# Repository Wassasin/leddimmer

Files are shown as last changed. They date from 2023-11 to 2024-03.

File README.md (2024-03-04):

# LED PWM dimmer
Quick low-side PWM device to crudely dim two 24V 4A LED strips.

Uses ESP32-C3 LEDC peripheral to provide the PWM signal, and uses two low side gate drivers to pull a N-channel Mosfet. Uses high side current limiters and fuses as protection.

## TODO
* 100K Pull-up esp32 enable
* 100K Pull-downs for drv-enable
* 47nF filter voor isense
* Swap drv2 isense en drvsense
* WS2812B data line on 3V3
* Status line high side driver useless without output voltages
* Caps C5750X7R1V476M230KC / 47uF 35V X7R 2220

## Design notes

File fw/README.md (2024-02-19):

## Dependencies
This project uses the Espressif [ESP-IDF version 5.1.1 for the ESP32S3](https://docs.espressif.com/projects/esp-idf/en/v5.1.1/esp32s3/get-started/index.html).

### Nix
Optionally you can use Nix to initialize a shell.

Firstly you require Nix to be installed, and to have the following optional features enabled (in `~/.config/nix/nix.conf`):
```
experimental-features = nix-command flakes
```

Then you can run in the top-level directory of this repository:
```bash
nix develop
```

All the required dependencies should now be loaded in this shell.

## How to build
```bash
rm ./sdkconfig
export SDKCONFIG_DEFAULTS="./sdkconfig.default"
idf.py clean
rm -rf build

idf.py menuconfig
# Now set all required options under Leddimmer

idf.py build
```

## How to flash
Connect the device over USB-C to your computer and run
```bash
idf.py flash
```

You can attach to the virtual terminal of the device by running
```bash
idf.py monitor
```

For more information to use this monitor, see the [ESP-idf documentation on monitor](https://docs.espressif.com/projects/esp-idf/en/release-v5.1/esp32s3/api-guides/tools/idf-monitor.html).

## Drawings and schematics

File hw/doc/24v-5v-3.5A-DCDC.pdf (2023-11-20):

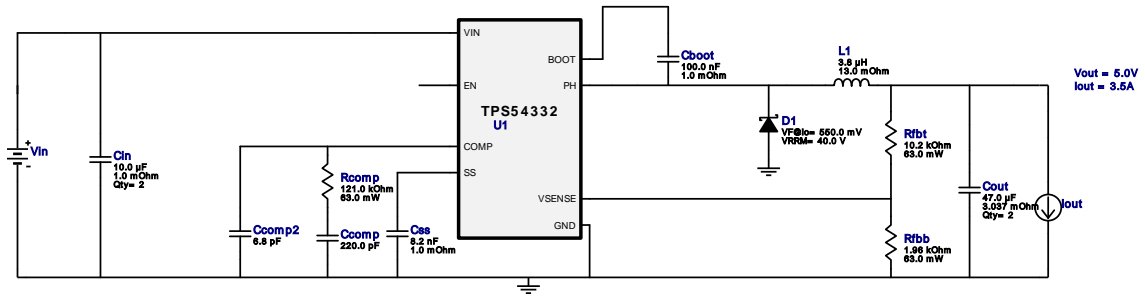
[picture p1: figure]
Css 8.2 nF 1.0 m Ohm; Ccom p2 6.8 pF; TPS5 4 3 3 2; BOOT; VIN; VSENSE; COMP; GND; Rfbb 1.96 kOhm 63.0 m W; Cboot 100.0 nF 1.0 m Ohm; Cin 10.0 µF 1.0 m Ohm Qty= 2; L1 3.8 µH 13.0 m Ohm; Rfbt 10.2 kOhm 63.0 m W; Cout 47.0 µF 3.037 m Ohm Qty= 2; D1 VF@Io= 550.0 m V VRRM= 40.0 V; Ccom p 220.0 pF; Rcom p 121.0 kOhm 63.0 m W; Vout = 5.0V Iout = 3.5A; Iout; Vin

Copyright © 2023, Texas Instruments Incorporated | 1 | ti.com/webench

WEBENCH®
Design Report TPS54332DDAR : TPS54332DDAR 23V-25V to 5.00V @ 3.5A November 18, 2023 08:35:46 GMT-06:00

## WEBENCH ® Design Report

Design : 88 TPS54332DDAR
TPS54332DDAR 23V-25V to 5.00V @ 3.5A

VinMin = 23.0V
VinMax = 25.0V
Vout = 5.0V
Iout = 3.5A

Device = TPS54332DDAR
Topology = Buck
Created = 2023-11-18 08:24:08.620 BOM Cost = $2.37
BOM Count = 14
Total Pd = 2.56W

## Electrical BOM

Name | Manufacturer | Part Number | Properties | Qty Price | Footprint
Cboot | MuRata | GRM155R71A104KA01D (http://search.murata.co.jp/Ceramy/PnsearchViewAction.do) Series= X7R | Cap= 100.0 nF ESR= 1.0 mOhm VDC= 10.0 V IRMS= 0.0 A
1 | $0.01
| | | | | 0402 3 mm²
Ccomp | Samsung Electro- Mechanics | CL21C221JBANNNC (http://www.samsungsem.com/servlet/FileDownload?type%3Dspec%26file%3DCL21C221JBANNNC.pdf) Series= C0G/NP0

Cap= 220.0 pF
VDC= 50.0 V
IRMS= 0.0 A

1 $0.01
0805 7 mm²
Ccomp2 | AVX | 06031U6R8BAT2A (http://www.avx.com/docs/Catalogs/ccog.pdf) Series= C0G/NP0

Cap= 6.8 pF
VDC= 100.0 V
IRMS= 0.0 A

1 $0.05
0603 5 mm²
Cin | TDK | C3225X7R1H106M250AC Series= X7R

Cap= 10.0 uF
ESR= 1.0 mOhm
VDC= 50.0 V
IRMS= 5.0 A

2 $0.27
1210 15 mm²
Cout | MuRata | GRM32ER61C476KE15L (http://psearch.en.murata.com/capacitor/result/smd/?status%3Dall%26pid%3DGRM32ER61C476KE15L) Series= X5R

Cap= 47.0 uF
ESR= 3.037 mOhm
VDC= 16.0 V
IRMS= 4.59346 A

2 $0.17
1210_280 15 mm²
Css | MuRata | GRM033R71A822KA01D (http://search.murata.co.jp/Ceramy/PnsearchViewAction.do) Series= X7R

Cap= 8.2 nF
ESR= 1.0 mOhm
VDC= 10.0 V
IRMS= 0.0 A

1 $0.01
0201 2 mm²
D1 | Diodes Inc. | B540C-13-F (http://www.diodes.com/datasheets/ds13012.pdf) | VF@Io= 550.0 mV VRRM= 40.0 V
1 | $0.19

SMC 83 mm²
L1 | Coiltronics | DR1040-3R8-R (http://www.cooperindustries.com/content/dam/public/bussmann/Electronics/Resources/Data%20Sheets/Bus%5FElx%5FDS%5FPM%204147%5FDR1040%5FSeries.pdf) | L= 3.8 µH 13.0 mOhm
1 | $0.49

DR1040 154 mm²
Rcomp | Vishay-Dale | CRCW0402121KFKED (http://www.vishay.com/docs/20035/dcrcwe3.pdf) Series= CRCW..e3

Res= 121.0 kOhm
Power= 63.0 mW
Tolerance= 1.0%

1 $0.01
0402 3 mm²
Rfbb | Vishay-Dale | CRCW04021K96FKED (http://www.vishay.com/docs/20035/dcrcwe3.pdf) Series= CRCW..e3

Res= 1.96 kOhm
Power= 63.0 mW
Tolerance= 1.0%

1 $0.01
0402 3 mm²

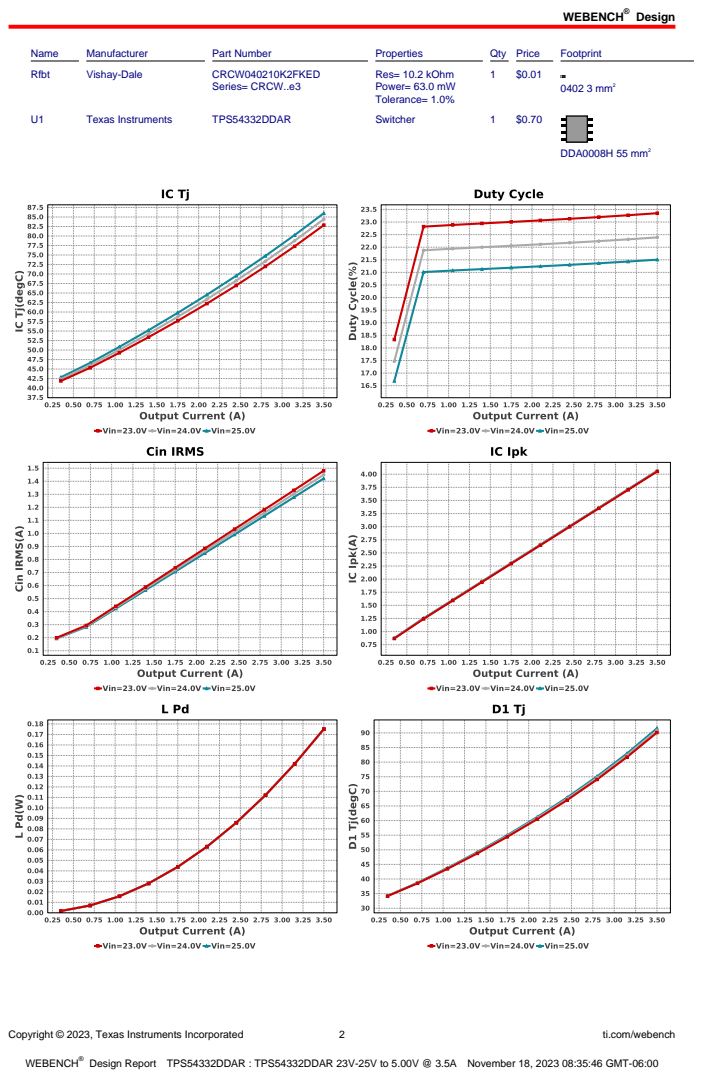
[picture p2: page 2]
Design; Copyright © 2023, Texas Instruments Incorporated; ti.com/webench; Name; Manufacturer; Part Number; Properties; Qty Price; Footprint; Rfbt; Vishay-Dale; CRCW040210K2FKED; Series= CRCW..e3; Res= 10.2 kOhm Power= 63.0 mW Tolerance= 1.0%; 0402 3 mm²; Texas Instruments; TPS54332DDAR; Switcher; DDA0008H 55 mm²

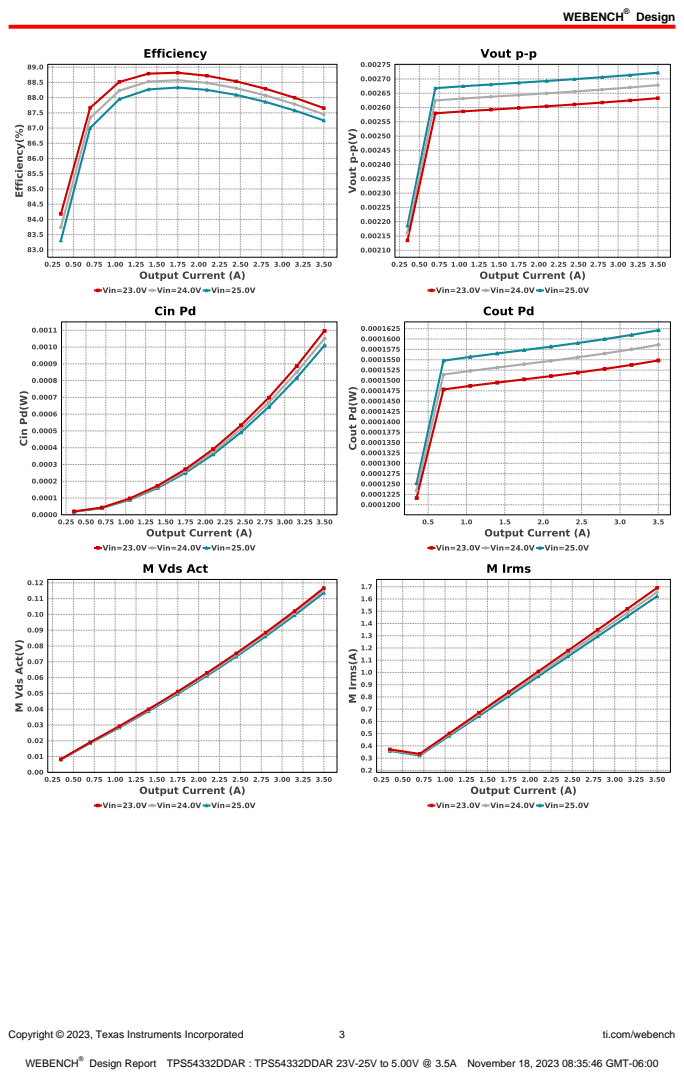
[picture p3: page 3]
Copyright © 2023, Texas Instruments Incorporated; ti.com/webench

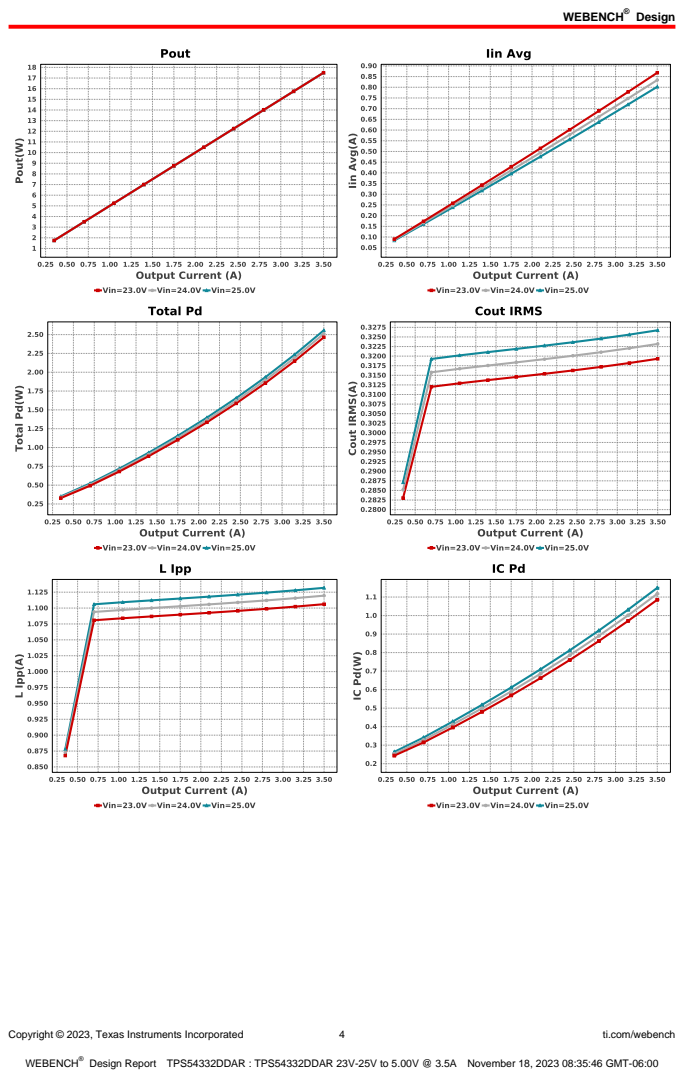
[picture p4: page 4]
Copyright © 2023, Texas Instruments Incorporated; ti.com/webench

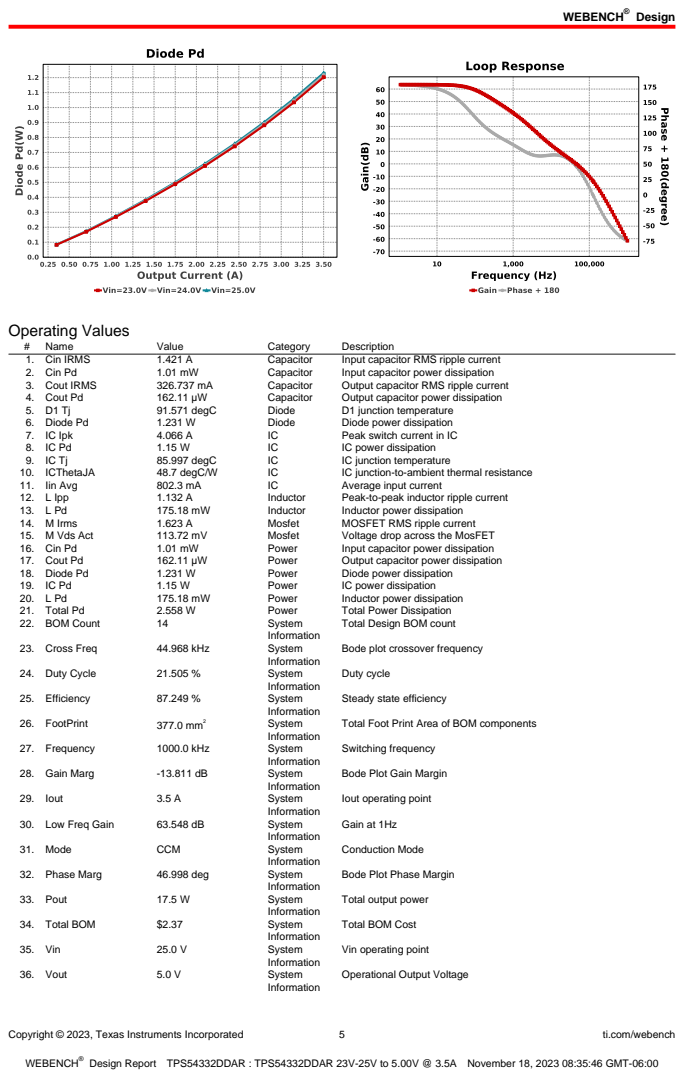
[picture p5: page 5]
Copyright © 2023, Texas Instruments Incorporated; ti.com/webench; Operating Values; Name; Value; Category; Description; 1. Cin IRMS; Capacitor; Input capacitor RMS ripple current; 2. Cin Pd; Input capacitor power dissipation; 3. Cout IRMS; Output capacitor RMS ripple current; 4. Cout Pd; Output capacitor power dissipation; 91.571 degC; Diode; D1 junction temperature; 6. Diode Pd; Diode power dissipation; 7. IC Ipk; Peak switch current in IC; IC power dissipation; 85.997 degC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

Total Design BOM count

Bode plot crossover frequency

Steady state efficiency

Total Foot Print Area of BOM components

Bode Plot Gain Margin

Iout operating point

Bode Plot Phase Margin

Total output power

Total BOM Cost

Vin operating point

Operational Output Voltage

Copyright © 2023, Texas Instruments Incorporated | 6 | ti.com/webench
# | Name | Value | Category | Description

37. Vout Actual | 4.963 V | System
| | | Information | Vout Actual calculated based on selected voltage divider resistors
38. Vout Tolerance | 5.254 % | System
| | | Information | Vout Tolerance based on IC Tolerance (no load) and voltage divider resistors if applicable
39. Vout p-p | 2.722 mV | System
| | | Information | Peak-to-peak output ripple voltage
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

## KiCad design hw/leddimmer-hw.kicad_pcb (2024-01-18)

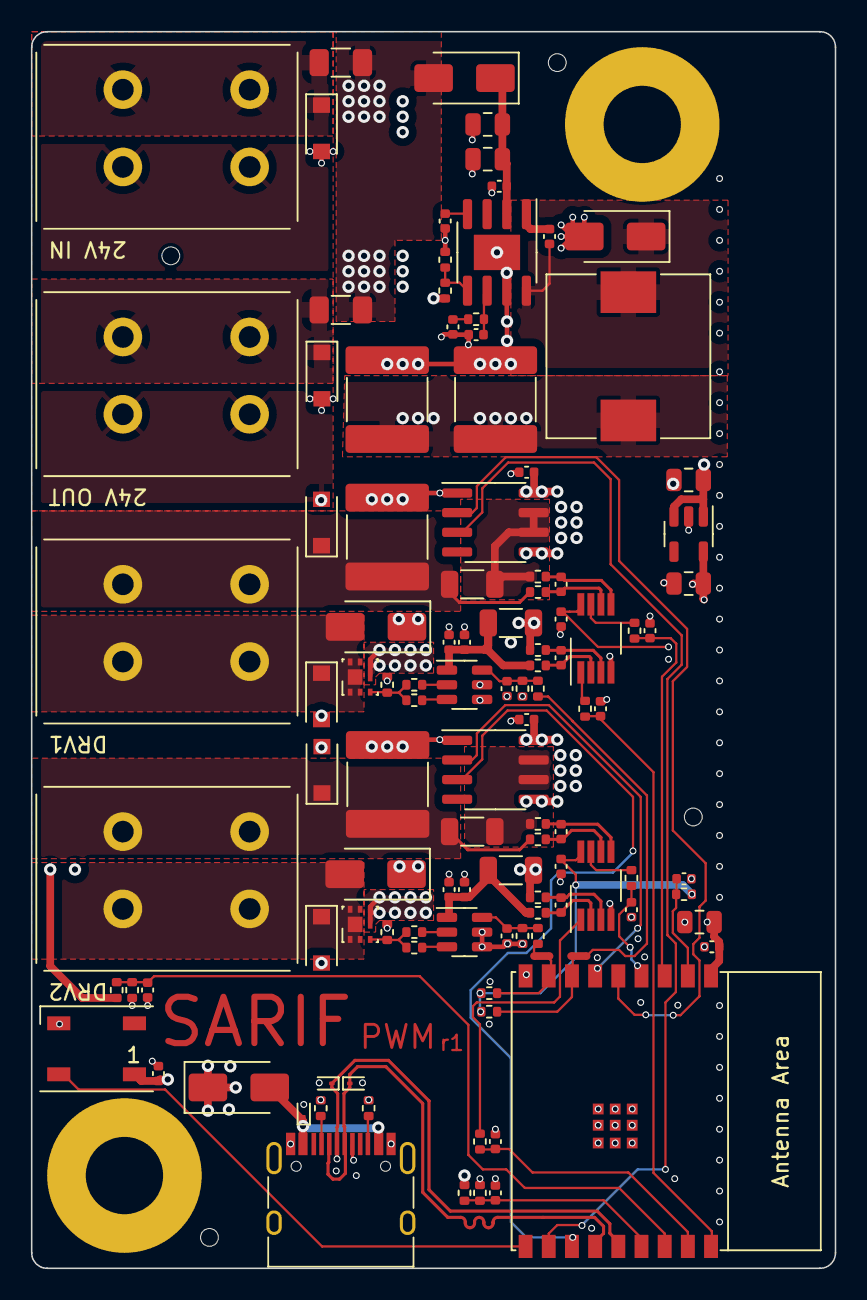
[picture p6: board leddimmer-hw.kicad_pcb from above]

Board: 4 copper layers, 52.0 x 80.0 mm, 117 parts (0 on the bottom side), 62 nets.

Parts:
C201, C204, C210, C301, C304, C310, C509, C601, C603, C604, C605, C606: 100nF; C_0402_1005Metric
C202, C205, C206, C302, C305, C306: C_0402_1005Metric
C203, C303, C505: 1uF; C_0402_1005Metric
C207, C307, C510, C511: 47uF; C_2220_5750Metric
C208, C209, C308, C309, C501: 6.8nF; C_0402_1005Metric
C502, C504, C602: 10uF; C_0805_2012Metric
C503: 220pF; C_0402_1005Metric
C506: 8.2nF; C_0402_1005Metric
C507, C508: 10u; C_0805_2012Metric
D201, D301, D501, D502, D503: SS54; D_SMA
D401: ESD9X5.0ST5G; D_SOD-923
D402, D403: ESD9L3.3ST5G; D_SOD-923
D404, D405, D406, D407, D408, D409: SJD12A28L01; D_SOD-123S
D601: WS2812B; LED_WS2812B_PLCC4_5.0x5.0mm_P3.2mm
F401, F402: 0501010.WR1; Fuse_1206_3216Metric
H101, H102, H103, H104: ToolingHole; JLCPCB tooling hole
H105, H106: MountingHole; MountingHole_5mm_Keepout
J401, J402, J403, J404: 2604-1102; WAGO-2604-1102
L501: SDSL10D40F-3R8Y; L_10.4x10.4_H4.8
NT601, NT602: NetTie_2; NetTie-2_SMD_Pad0.5mm
P401: TYPE-C-31-M-12; USB_C_Receptacle_HRO_TYPE-C-31-M-12
Q201, Q301: CSD17571Q2
R201, R203, R204, R207, R208, R209, R210, R301, R303, R304, R307, R308, R309, R310: 1Ohm; R_0402_1005Metric
R202, R211, R302, R311, R601, R602, R603, R604, R606: 100kOhm; R_0402_1005Metric
R205, R206, R305, R306: 3mR 1%; R_1206_3216Metric
R212, R213, R312, R313, R401, R402: 5.1kOhm; R_0402_1005Metric
R501: 121kOhm; R_0402_1005Metric
R502, R607: 10.2kOhm; R_0402_1005Metric
R503, R605: 1.96kOhm; R_0402_1005Metric
U201, U301: NCV8460A; SOIC-8_3.9x4.9mm_P1.27mm
U202, U302: UCC27511DBVR; SOT-23-6
U203, U303: INA2180A2IDGKR; VSSOP-8_3.0x3.0mm_P0.65mm
U501: TPS54332DDAR; SOIC-8-1EP_3.9x4.9mm_P1.27mm_EP2.29x3mm
U502: AP2112K-3.3; SOT-23-5
U601: ESP32-C3-WROOM-02

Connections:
+3V3: C210.1, C310.1, C508.1, C602.1, C603.1, R601.2, R602.2, R603.2, U203.8 (VS), U303.8 (VS), U502.5 (VOUT), U601.1 (3V3)
+5V: C507.1, C510.1, C511.1, C604.1, D502.1 (K), D601.1 (VDD), L501.2, R205.1, R207.2, R305.1, R307.2, R502.2, R606.2, U502.1 (VIN), U502.3 (EN)
+24V: C201.1, C301.1, D201.1 (K), D301.1 (K), D501.2 (A), F401.1, F402.1, R604.2, U201.5 (VD), U201.8 (VD), U301.5 (VD), U301.8 (VD)
/Connectors/24V_1: D404.1 (K), F401.2, J401.1
/Connectors/24V_2: D409.1 (K), F402.2, J404.1
/Connectors/DRV1+: C207.1, D405.1 (K), J402.1, R206.1, R210.2
/Connectors/DRV1-: D201.2 (A), D407.1 (K), J402.2, Q201.1 (D)
/Connectors/DRV2+: C307.1, D406.1 (K), J403.1, R306.1, R310.2
/Connectors/DRV2-: D301.2 (A), D408.1 (K), J403.2, Q301.1 (D)
/Connectors/USB_CC1: P401.A5 (CC1), R401.1
/Connectors/USB_CC2: P401.B5 (CC2), R402.1
/Connectors/USB_D+: D403.1 (K), P401.A6 (D+), P401.B6 (D+), U601.14 (GPIO19/USB_D+)
/Connectors/USB_D-: D402.1 (K), P401.A7 (D-), P401.B7 (D-), U601.13 (GPIO18/USB_D-)
/Driver 1/24V_SWITCHED: R204.2, R206.2, U201.6 (OUT), U201.7 (OUT)
/Driver 1/+5V_DRV: C203.1, C204.1, R203.2, R205.2, U202.1 (V_{DD})
/Driver 1/DRVMON: C209.1, R213.2, U601.18 (GPIO0/ADC1_CH0/XTAL_32K_P)
/Driver 1/DRVSENSE: R213.1, U203.1 (OUT1)
/Driver 1/DRVSENSE+: C205.2, R207.1, U203.3 (IN+1)
/Driver 1/DRVSENSE-: C205.1, R203.1, U203.2 (IN-1)
/Driver 1/ENABLE: U201.2 (IN), U601.5 (GPIO6)
/Driver 1/GATE: Q201.2 (G), R208.2, R209.1, R211.2
/Driver 1/GATEH: R208.1, U202.2 (OUTH)
/Driver 1/GATEL: R209.2, U202.3 (OUTL)
/Driver 1/IMON: C208.1, R212.2, U601.3 (GPIO4/ADC1_CH4)
/Driver 1/ISENSE: R212.1, U203.7 (OUT2)
/Driver 1/ISENSE+: C206.1, R204.1, U203.5 (IN+2)
/Driver 1/ISENSE-: C206.2, R210.1, U203.6 (IN-2)
/Driver 1/PWM: NT601.2, R201.1
/Driver 1/PWM_FILT: C202.1, R201.2, R202.2, U202.6 (IN+)
/Driver 1/STAT: U201.3 (STAT), U601.11 (GPIO20/U0RXD)
/Driver 2/24V_SWITCHED: R304.2, R306.2, U301.6 (OUT), U301.7 (OUT)
/Driver 2/+5V_DRV: C303.1, C304.1, R303.2, R305.2, U302.1 (V_{DD})
/Driver 2/DRVMON: C309.1, R313.2, U601.17 (GPIO1/ADC1_CH1/XTAL_32K_N)
/Driver 2/DRVSENSE: R313.1, U303.1 (OUT1)
/Driver 2/DRVSENSE+: C305.2, R307.1, U303.3 (IN+1)
/Driver 2/DRVSENSE-: C305.1, R303.1, U303.2 (IN-1)
/Driver 2/ENABLE: U301.2 (IN), U601.6 (GPIO7)
/Driver 2/GATE: Q301.2 (G), R308.2, R309.1, R311.2
/Driver 2/GATEH: R308.1, U302.2 (OUTH)
/Driver 2/GATEL: R309.2, U302.3 (OUTL)
/Driver 2/IMON: C308.1, R312.2, U601.4 (GPIO5/ADC2_CH0)
/Driver 2/ISENSE: R312.1, U303.7 (OUT2)
/Driver 2/ISENSE+: C306.1, R304.1, U303.5 (IN+2)
/Driver 2/ISENSE-: C306.2, R310.1, U303.6 (IN-2)
/Driver 2/PWM: NT602.2, R301.1
/Driver 2/PWM_FILT: C302.1, R301.2, R302.2, U302.6 (IN+)
/Driver 2/STAT: U301.3 (STAT), U601.12 (GPIO21/U0TXD)
/MCU/5V_MEAS: C606.1, R606.1, R607.2, U601.15 (GPIO3/ADC1_CH3)
/MCU/24V_MEAS: C605.1, R604.1, R605.2, U601.16 (GPIO2/ADC1_CH2)
/MCU/EN: C601.1, R603.1, U601.2 (EN/CHIP_PU)
/MCU/IO8_STRAP: NT601.1, R601.1, U601.7 (GPIO8)
/MCU/IO9_STRAP: NT602.1, R602.1, U601.8 (GPIO9)
/MCU/LED: D601.4 (DIN), U601.10 (GPIO10)
/Power/5V_BOOT: C509.2, U501.1 (BOOT)
/Power/5V_COMP: C501.1, R501.2, U501.6 (COMP)
/Power/5V_PH: C509.1, D503.1 (K), L501.1, U501.8 (PH)
/Power/5V_SS: C506.1, U501.4 (SS)
/Power/5V_VSENSE: R502.1, R503.2, U501.5 (VSENSE)
/Power/24V_FILT: C502.1, C504.1, C505.1, D501.1 (K), U501.2 (VIN)
GND: C201.2, C202.2, C203.2, C204.2, C207.2, C208.2, C209.2, C210.2, C301.2, C302.2, C303.2, C304.2, C307.2, C308.2, C309.2, C310.2, C501.2, C502.2, C503.2, C504.2, C505.2, C506.2, C507.2, C508.2, C510.2, C511.2, C601.2, C602.2, C603.2, C604.2, C605.2, C606.2, D401.2 (A), D402.2 (A), D403.2 (A), D404.2 (A), D405.2 (A), D406.2 (A), D407.2 (A), D408.2 (A), D409.2 (A), D503.2 (A), D601.3 (VSS), J401.2, J404.2, P401.A1 (GND), P401.A12 (GND), P401.B1 (GND), P401.B12 (GND), P401.S1 (SHIELD), Q201.3 (S), Q301.3 (S), R202.1, R211.1, R302.1, R311.1, R401.2, R402.2, R503.1, R605.1, R607.1, U201.1 (GND), U202.4 (GND), U202.5 (IN-), U203.4 (GND), U301.1 (GND), U302.4 (GND), U302.5 (IN-), U303.4 (GND), U501.7 (GND), U501.9 (GND), U502.2 (GND), U601.9 (GND), U601.19 (GND)
unnamed: C503.1, R501.1
VBUS: D401.1 (K), D502.2 (A), P401.A4 (VBUS), P401.A9 (VBUS), P401.B4 (VBUS), P401.B9 (VBUS)

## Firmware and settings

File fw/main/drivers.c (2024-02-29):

#include "drivers.h"

#include <driver/ledc.h>
#include <freertos/FreeRTOS.h>
#include <freertos/semphr.h>
#include <string.h>

#include "power.h"
#include "util.h"

#define TAG "drivers"

#define LEDC_TIMER LEDC_TIMER_0
#define LEDC_MODE LEDC_LOW_SPEED_MODE
#define LEDC_DUTY_RES LEDC_TIMER_11_BIT
#define LEDC_FREQUENCY (30000)

#define LEDC_DRIVER1_CHANNEL (LEDC_CHANNEL_0)
#define LEDC_DRIVER2_CHANNEL (LEDC_CHANNEL_1)

#define GPIO_DRIVER1_PWM (8)
#define GPIO_DRIVER2_PWM (9)
#define GPIO_DRIVER1_EN (6)
#define GPIO_DRIVER2_EN (7)

typedef struct
{
    gpio_num_t high_side_gpio_num;
    gpio_num_t low_side_gpio_num;
    ledc_channel_t ledc_channel;
} driver_description_t;

static const driver_description_t s_descriptions[DRIVERS_COUNT] = {
    {
        .high_side_gpio_num = GPIO_DRIVER1_EN,
        .low_side_gpio_num = GPIO_DRIVER1_PWM,
        .ledc_channel = LEDC_DRIVER1_CHANNEL,
    },
    {
        .high_side_gpio_num = GPIO_DRIVER2_EN,
        .low_side_gpio_num = GPIO_DRIVER2_PWM,
        .ledc_channel = LEDC_DRIVER2_CHANNEL,
    }
};

static drivers_pwm11_t s_state;
static SemaphoreHandle_t s_mutex;

static esp_err_t channel_config(ledc_channel_t channel, int gpio_num)
{
    ledc_channel_config_t config = {
        .speed_mode = LEDC_MODE,
        .channel = channel,
        .timer_sel = LEDC_TIMER,
        .intr_type = LEDC_INTR_DISABLE,
        .gpio_num = gpio_num,
        .duty = 0x00,
        .hpoint = 0
    };
    return ledc_channel_config(&config);
}

static bool drivers_persist_channel_unsafe(ledc_channel_t channel, driver_pwm11_t duty)
{
    if (duty == 0x00) {
        ESP_ERROR_CHECK(ledc_stop(LEDC_MODE, channel, 0));
    } else {
        ESP_ERROR_CHECK(ledc_set_duty(LEDC_MODE, channel, duty));
        ESP_ERROR_CHECK(ledc_update_duty(LEDC_MODE, channel));
    }
    return duty > 0;
}

static void drivers_persist_unsafe(void)
{
    for (size_t driver_i = 0; driver_i < DRIVERS_COUNT; ++driver_i) {
        const driver_description_t* description = &s_descriptions[driver_i];

        driver_pwm11_t computed_pwm = 0;
        if (power_low_side_unlocked(driver_i)) {
            computed_pwm = s_state[driver_i];
        }

        drivers_persist_channel_unsafe(description->ledc_channel, computed_pwm);
        bool enabled_high_side = power_high_side_unlocked(driver_i);

        gpio_set_level(description->high_side_gpio_num, enabled_high_side);
    }
}

esp_err_t drivers_init(void)
{
    s_mutex = xSemaphoreCreateMutex();

    gpio_config_t io_conf = {
        .intr_type = GPIO_INTR_DISABLE,
        .mode = GPIO_MODE_OUTPUT,
        .pin_bit_mask = (1ULL << GPIO_DRIVER1_EN) | (1ULL << GPIO_DRIVER2_EN),
        .pull_down_en = 0,
        .pull_up_en = 0,
    };
    gpio_config(&io_conf);

    ledc_timer_config_t ledc_timer = {
        .speed_mode = LEDC_MODE,
        .timer_num = LEDC_TIMER,
        .duty_resolution = LEDC_DUTY_RES,
        .freq_hz = LEDC_FREQUENCY,
        .clk_cfg = LEDC_AUTO_CLK
    };
    ESP_ERROR_CHECK(ledc_timer_config(&ledc_timer));

    ESP_ERROR_CHECK(channel_config(LEDC_DRIVER1_CHANNEL, GPIO_DRIVER1_PWM));
    ESP_ERROR_CHECK(channel_config(LEDC_DRIVER2_CHANNEL, GPIO_DRIVER2_PWM));

    drivers_persist_unsafe();

    return ESP_OK;
}

esp_err_t drivers_command(uint8_t driver_i, driver_pwm11_t duty)
{
    if (driver_i > ARRAY_SIZE(s_state)) {
        return ESP_ERR_INVALID_ARG;
    }

    if (duty > DRIVER_PWM_MAX) {
        duty = DRIVER_PWM_MAX;
    }

    xSemaphoreTake(s_mutex, portMAX_DELAY);
    s_state[driver_i] = duty;
    drivers_persist_unsafe();
    xSemaphoreGive(s_mutex);

    return ESP_OK;
}

void drivers_update(void)
{
    xSemaphoreTake(s_mutex, portMAX_DELAY);
    drivers_persist_unsafe();
    xSemaphoreGive(s_mutex);
}

void drivers_fetch(drivers_pwm11_t* duty_out)
{
    xSemaphoreTake(s_mutex, portMAX_DELAY);
    memcpy(*duty_out, s_state, sizeof(s_state));
    xSemaphoreGive(s_mutex);
}

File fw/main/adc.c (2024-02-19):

#include "adc.h"

#include <esp_log.h>
#include <freertos/FreeRTOS.h>
#include <freertos/semphr.h>
#include <freertos/task.h>
#include <math.h>
#include <string.h>

#include <esp_adc/adc_cali.h>
#include <esp_adc/adc_cali_scheme.h>
#include <esp_adc/adc_continuous.h>

#include "events.h"
#include "util.h"

#define TAG "adc"

#define ADC_BIT_WIDTH (SOC_ADC_DIGI_MAX_BITWIDTH)

#define ADC_ATTEN ADC_ATTEN_DB_0 /* Up to 750mV */
#define ADC_RAW_RANGE (1 << ADC_BIT_WIDTH)

#define ADC_CHANNEL(adc_channel_nr) ADC_CHANNEL_##adc_channel_nr

typedef struct {
    adc_unit_t unit;
    adc_channel_t channel;
} adc_source_t;

#define ADC_SOURCE(adc_unit, adc_channel) ((adc_source_t) { unit: adc_unit, channel: ADC_CHANNEL(adc_channel) })

static adc_source_t adc_sources[4] = {
    ADC_SOURCE(ADC_UNIT_1, 2),
    ADC_SOURCE(ADC_UNIT_1, 3),
    ADC_SOURCE(ADC_UNIT_1, 4),
    ADC_SOURCE(ADC_UNIT_1, 0),
};

#define ADC_OVERSAMPLING 4
#define SAMPLES_COUNT ARRAY_SIZE(adc_sources)
#define ADC_FRAME_LEN (SOC_ADC_DIGI_DATA_BYTES_PER_CONV * SAMPLES_COUNT * ADC_OVERSAMPLING)

typedef struct
{
    uint32_t min;
    uint32_t max;
    uint32_t rms;
    uint32_t count;
} sample_intermediate_t;

static TaskHandle_t s_task_handle;
static SemaphoreHandle_t s_mutex;

static adc_cali_handle_t s_cali_handles[1];
static adc_samples_t s_samples;

static uint32_t min(uint32_t x, uint32_t y)
{
    return (x < y) ? x : y;
}

static uint32_t max(uint32_t x, uint32_t y)
{
    return (y < x) ? x : y;
}

static uint32_t raw_to_millivolts(adc_unit_t unit, uint32_t raw)
{
    int voltage;
    ESP_ERROR_CHECK(adc_cali_raw_to_voltage(s_cali_handles[unit], raw, &voltage));
    return voltage;
}

static adc_sample_t sample_voltage_divider(adc_sample_t sample, uint32_t r1, uint32_t r2)
{
    sample.rms = ((uint32_t)sample.rms) * (r1 + r2) / r2;
    sample.max = ((uint32_t)sample.max) * (r1 + r2) / r2;
    return sample;
}

static adc_sample_t sample_current_sense(adc_sample_t sample, uint32_t r_mohm, uint32_t amplification)
{
    sample.rms = ((uint32_t)sample.rms) * 1000 / r_mohm / amplification;
    sample.max = ((uint32_t)sample.max) * 1000 / r_mohm / amplification;
    return sample;
}

static adc_sample_t sample_from_intermediate(sample_intermediate_t sample_intermediate)
{
    uint16_t rms = sqrt(sample_intermediate.rms / sample_intermediate.count);

    return (adc_sample_t) {
        .max = sample_intermediate.max,
        .rms = rms,
    };
}

typedef sample_intermediate_t samples_intermediate_t[SAMPLES_COUNT];

static void samples_from_intermediate(const samples_intermediate_t sample_intermediate, adc_samples_t* samples)
{
    samples->vbus_mv = sample_voltage_divider(sample_from_intermediate(sample_intermediate[0]), 10000, 196);
    samples->vdrv_mv = sample_voltage_divider(sample_from_intermediate(sample_intermediate[1]), 10000, 1020);

    // samples->drivers_drv_ma[0] = sample_current_sense(sample_from_intermediate(sample_intermediate[2]), 3, 50);
    // samples->drivers_drv_ma[1] = sample_current_sense(sample_from_intermediate(sample_intermediate[3]), 3, 50);

    samples->drivers_out_ma[0] = sample_current_sense(sample_from_intermediate(sample_intermediate[2]), 3, 50);
    samples->drivers_out_ma[1] = sample_current_sense(sample_from_intermediate(sample_intermediate[3]), 3, 50);
}

static bool IRAM_ATTR s_conv_done_cb(adc_continuous_handle_t handle, const adc_continuous_evt_data_t* edata, void* user_data)
{
    BaseType_t must_yield = pdFALSE;
    // Notify that ADC continuous driver has done enough number of conversions
    vTaskNotifyGiveFromISR(s_task_handle, &must_yield);

    return (must_yield == pdTRUE);
}

static void continuous_adc_init(adc_continuous_handle_t* out_handle)
{
    adc_continuous_handle_t handle = NULL;

    adc_continuous_handle_cfg_t adc_config = {
        .max_store_buf_size = 1024,
        .conv_frame_size = ADC_FRAME_LEN,
    };
    ESP_ERROR_CHECK(adc_continuous_new_handle(&adc_config, &handle));

    adc_continuous_config_t dig_cfg = {
        .sample_freq_hz = 30000,
        .conv_mode = ADC_CONV_SINGLE_UNIT_1,
        .format = ADC_DIGI_OUTPUT_FORMAT_TYPE2,
    };

    adc_digi_pattern_config_t adc_pattern[SOC_ADC_PATT_LEN_MAX] = { 0 };

    dig_cfg.pattern_num = ARRAY_SIZE(adc_sources);
    for (int i = 0; i < ARRAY_SIZE(adc_sources); i++) {
        adc_pattern[i] = (adc_digi_pattern_config_t) {
            .atten = ADC_ATTEN,
            .channel = adc_sources[i].channel,
            .unit = adc_sources[i].unit,
            .bit_width = ADC_BIT_WIDTH,
        };
    }
    dig_cfg.adc_pattern = adc_pattern;
    ESP_ERROR_CHECK(adc_continuous_config(handle, &dig_cfg));

    *out_handle = handle;
}
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

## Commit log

2023-11-20 Sent rev1 to factory
    [connectors.kicad_sch, driver.kicad_sch, leddimmer-hw.kicad_pcb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]
2024-01-18 Fixed some bugs
    [driver.kicad_sch, leddimmer-hw.kicad_pcb]
2024-01-18 Removed R{1,2}02 pull-down because it ruins strap
    [connectors.kicad_sch, driver.kicad_sch, mcu.kicad_sch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]
2024-02-19 Reworked ADC imon line
    [adc.c]
2024-02-19 WIP partitions and LED controller
    [partitions.csv]
2024-02-27 Progress on adding power control
    [partitions.csv]
2024-02-27 Implemented power fault lockout

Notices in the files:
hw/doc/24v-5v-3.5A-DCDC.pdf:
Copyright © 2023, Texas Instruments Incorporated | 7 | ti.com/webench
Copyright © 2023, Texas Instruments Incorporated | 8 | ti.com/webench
